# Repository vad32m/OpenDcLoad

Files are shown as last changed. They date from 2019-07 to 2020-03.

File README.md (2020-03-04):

#### Configurable parameters

| Configurable parameter | Range | Granularity | Number of Values |
| --- | --- | --- | --- |
| Current (CC mode) | 0 - 10 A | 10 mA | 1000 |
| Voltage (CV mode) | 1 - 10 V | 10 mV | 900 |
| | 10 - 100 V | 100 mV | 900 |
| | 100 - 360 V  | 1 V | 260 |
| Resistance (CR mode) | 0.5 - 10 Ohm | 50 mOhm | 190 |
| | 10 - 200 Ohm | 500 mOhm | 190 |
| Power (CP mode) | ???? | ???? | ???? |

#### Limits

| Limit type | Applicable mode | Limit value |
| --- | --- | --- |
| Power | All modes | 100 W max |
| Current | All modes | 10 A max |
| Voltage | All modes | 1 - 360 V |
| Resistance | All modes | 0.5 Ohm min |

#### Measured values

| Measured parameter | Range | Precision | Number of Values |
| --- | --- | --- | --- |
| Current | 0 - 1 A | 1 mA | 1000 |
| | 1 - 10 A | 10 mA | 900 |
| Voltage | 1 - 10 V | 10 mV | 900 |
| | 10 - 360 V | 100 mV | 3500 |

#### Parts

Power transistor - IRFP350

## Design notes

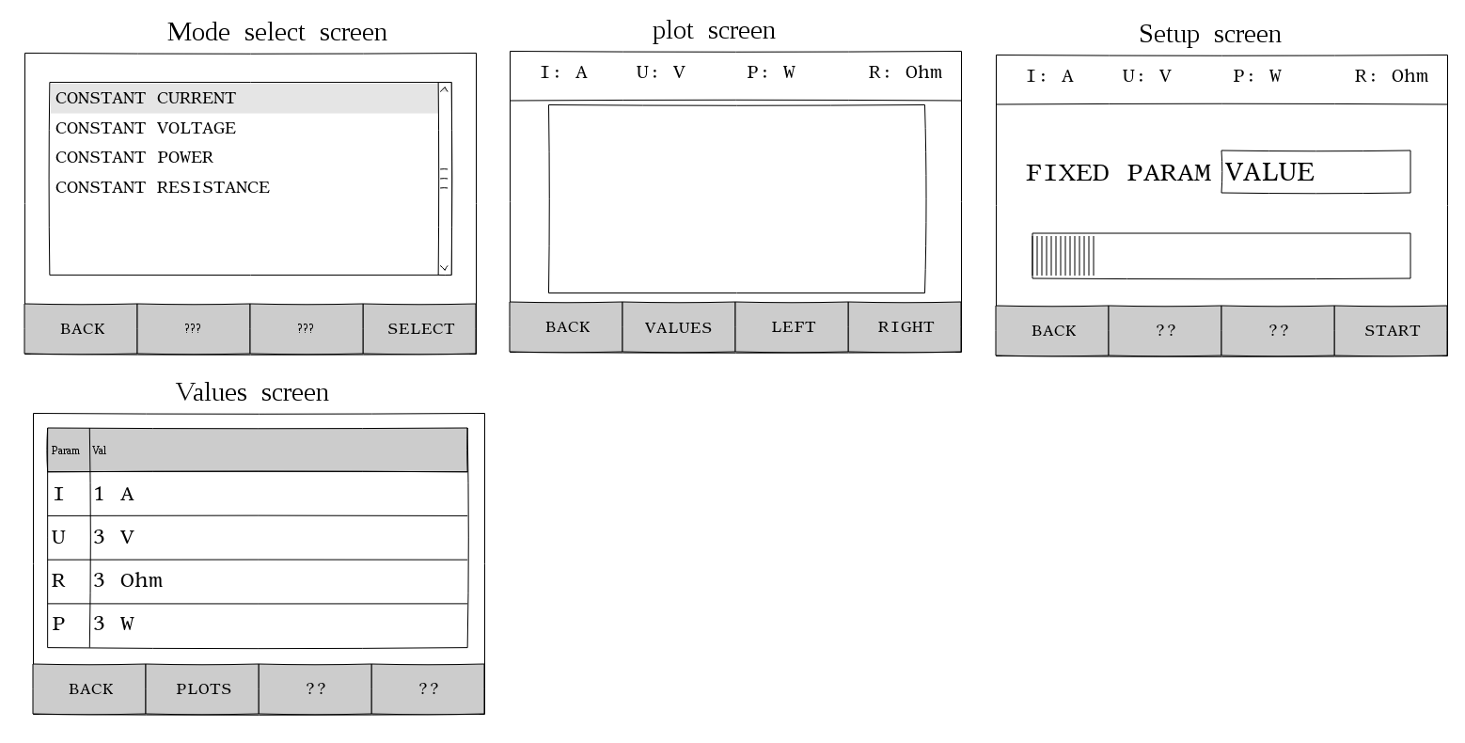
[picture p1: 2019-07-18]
doc/ui_wireframes.png

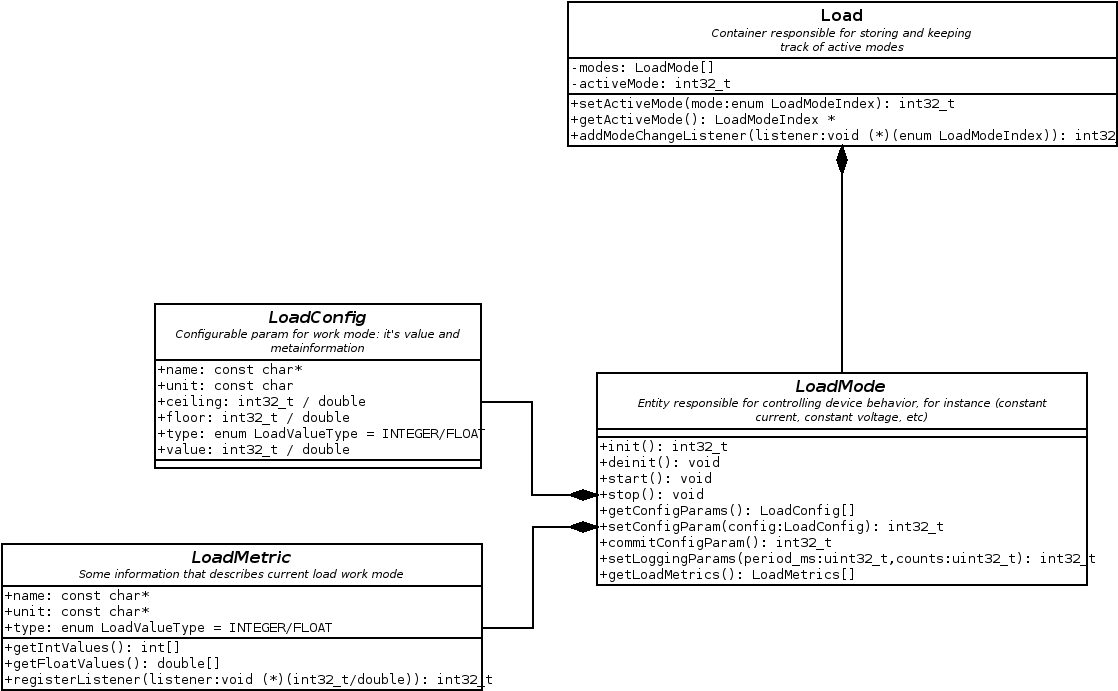
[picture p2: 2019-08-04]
doc/entities.png

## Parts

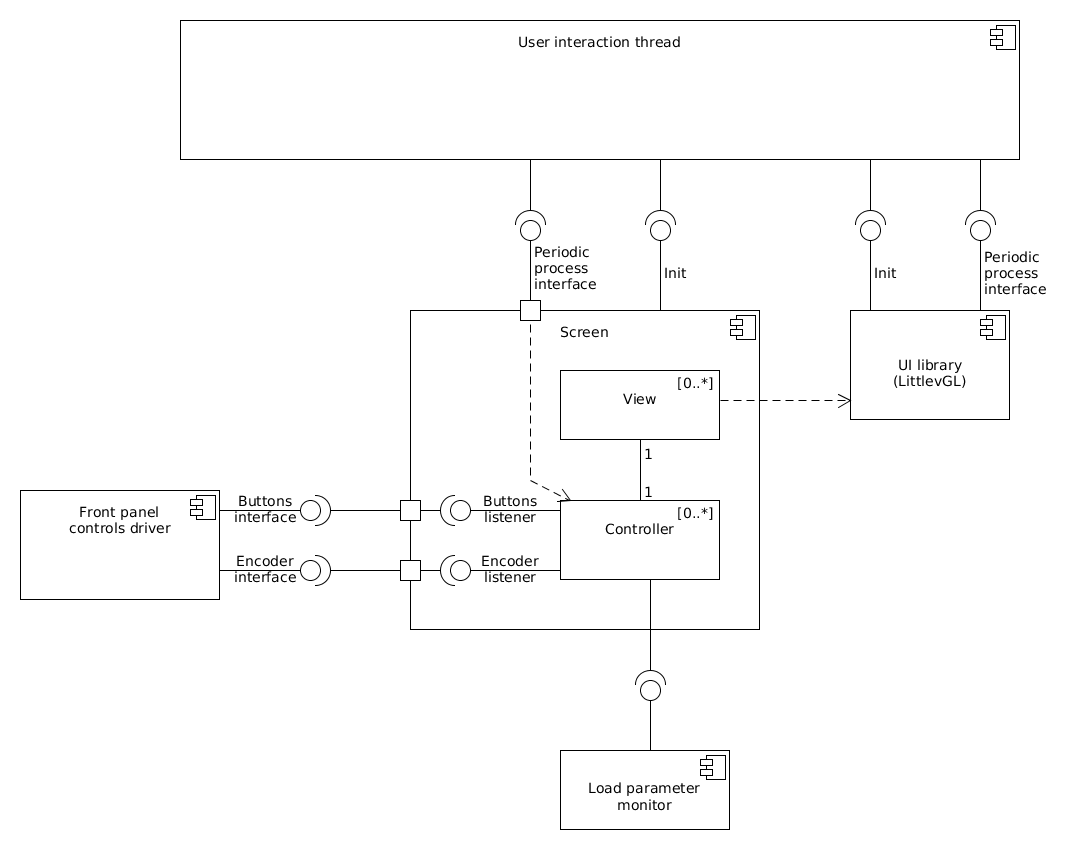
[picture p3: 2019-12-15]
doc/components.png

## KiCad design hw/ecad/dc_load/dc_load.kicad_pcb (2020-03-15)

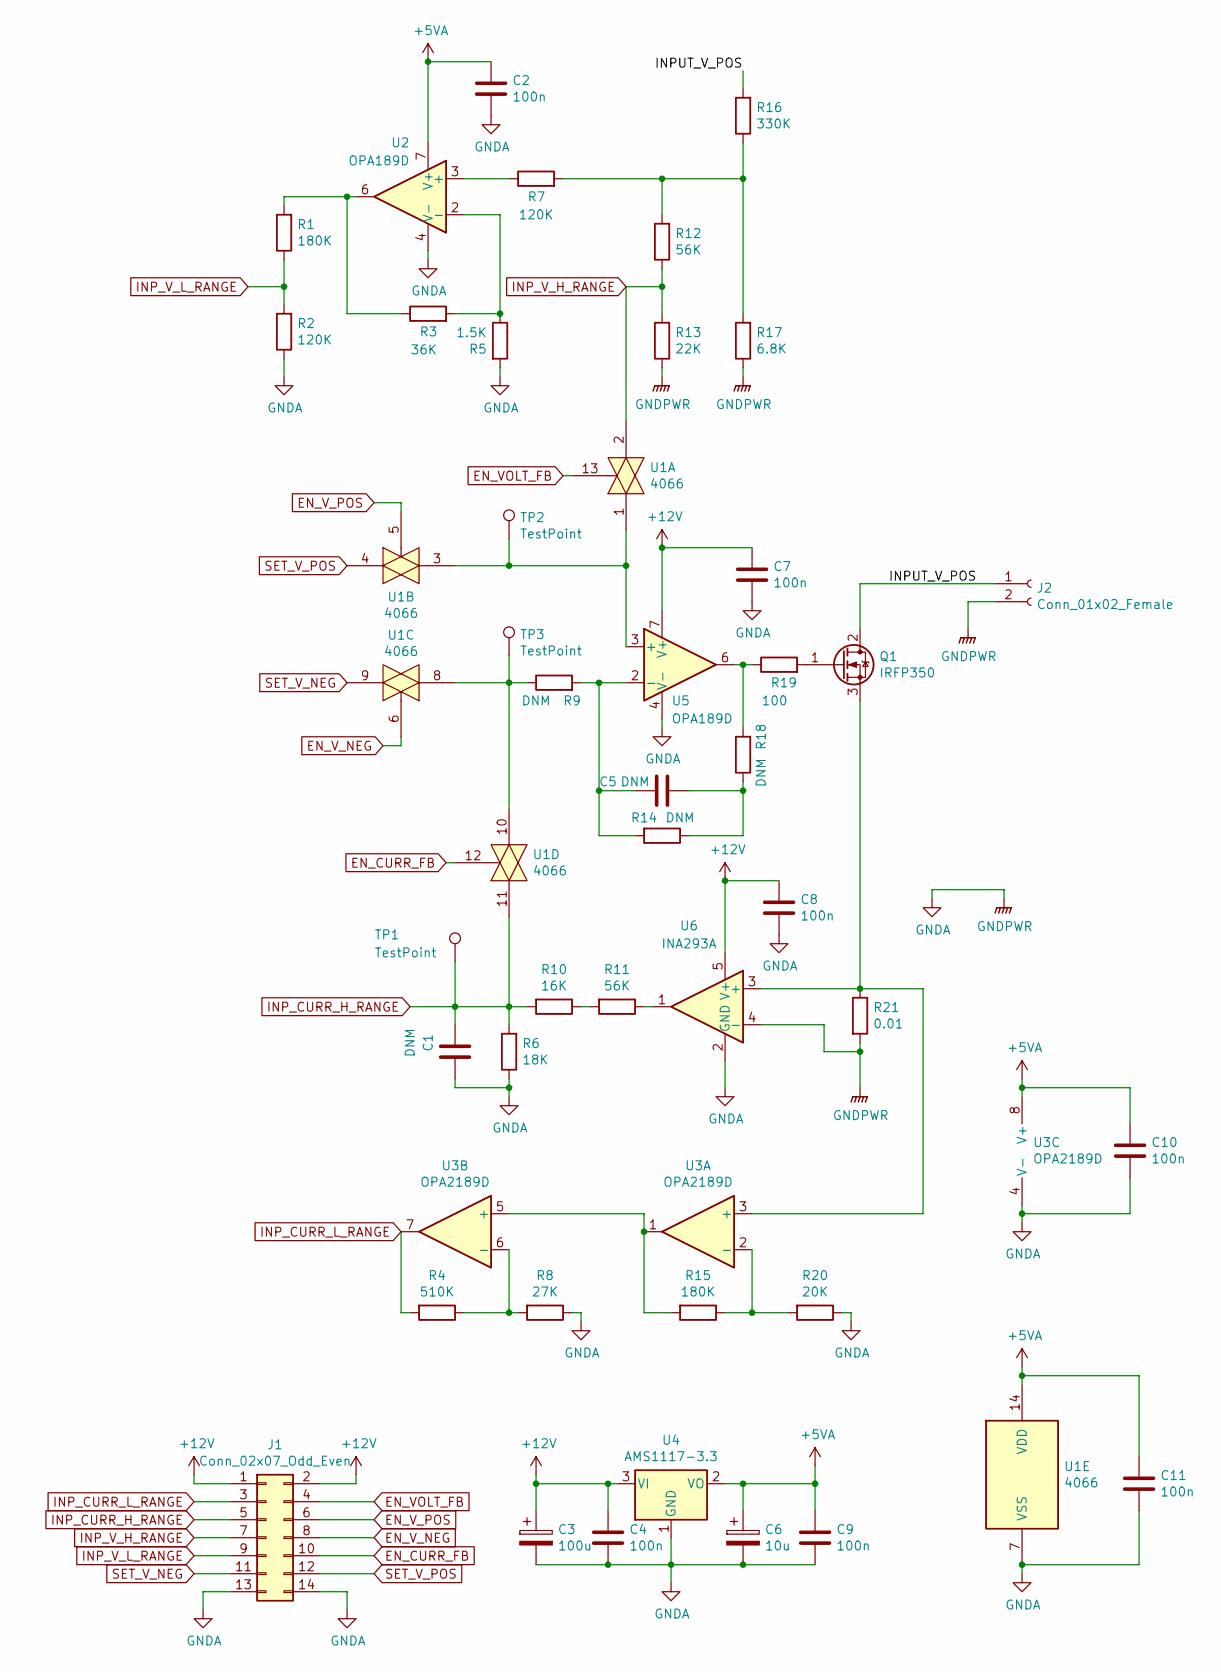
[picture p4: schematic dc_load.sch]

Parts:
C1, C5: DNM; C_0805_2012Metric_Pad1.15x1.40mm_HandSolder
C2, C4, C7, C8, C9, C10, C11: 100n; C_0805_2012Metric_Pad1.15x1.40mm_HandSolder
C3: 100u; CP_Radial_D7.5mm_P2.50mm
C6: 10u; CP_Radial_D5.0mm_P2.00mm
J1: Conn_02x07_Odd_Even; IDC-Header_2x07_P2.54mm_Vertical
J2: Conn_01x02_Female; SolderWirePad_1x02_P5.08mm_Drill1.5mm
Q1: IRFP350; TO-247-3_Horizontal_TabDown
R1, R15: 180K; R_0805_2012Metric_Pad1.15x1.40mm_HandSolder
R2, R7: 120K; R_0805_2012Metric_Pad1.15x1.40mm_HandSolder
R3: 36K; R_0805_2012Metric_Pad1.15x1.40mm_HandSolder
R4: 510K; R_0805_2012Metric_Pad1.15x1.40mm_HandSolder
R5: 1.5K; R_0805_2012Metric_Pad1.15x1.40mm_HandSolder
R6: 18K; R_0805_2012Metric_Pad1.15x1.40mm_HandSolder
R8: 27K; R_0805_2012Metric_Pad1.15x1.40mm_HandSolder
R9, R14, R18: DNM; R_0805_2012Metric_Pad1.15x1.40mm_HandSolder
R10: 16K; R_0805_2012Metric_Pad1.15x1.40mm_HandSolder
R11, R12: 56K; R_0805_2012Metric_Pad1.15x1.40mm_HandSolder
R13: 22K; R_0805_2012Metric_Pad1.15x1.40mm_HandSolder
R16: 330K; R_0805_2012Metric_Pad1.15x1.40mm_HandSolder
R17: 6.8K; R_0805_2012Metric_Pad1.15x1.40mm_HandSolder
R19: 100; R_0805_2012Metric_Pad1.15x1.40mm_HandSolder
R20: 20K; R_0805_2012Metric_Pad1.15x1.40mm_HandSolder
R21: 0.01; R_4020_10251Metric_Pad1.65x5.30mm_HandSolder
TP1, TP2, TP3: TestPoint; TestPoint_Pad_D1.5mm
U1: 4066; SOIC-14_3.9x8.7mm_P1.27mm
U2, U5: OPA189D; SOIC-8_3.9x4.9mm_P1.27mm
U3: OPA2189D; SOIC-8_3.9x4.9mm_P1.27mm
U4: AMS1117-3.3; SOT-223-3_TabPin2
U6: INA293A; SOT-23-5

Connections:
+5VA: C2.1, C6.1, C9.1, C10.1, C11.1, U1.14 (VDD), U2.7 (V+), U3.8 (V+), U4.2 (VO)
+12V: C3.1, C4.1, C7.1, C8.1, J1.1, J1.2, U4.3 (VI), U5.7 (V+), U6.5 (V+)
/INPUT_V_POS: J2.1, Q1.2 (D), R16.2
EN_CURR_FB: J1.10, U1.12
EN_VOLT_FB: J1.4, U1.13
EN_V_NEG: J1.8, U1.6
EN_V_POS: J1.6, U1.5
GNDA: C1.2, C2.2, C3.2, C4.2, C6.2, C7.2, C8.2, C9.2, C10.2, C11.2, J1.13, J1.14, J2.2, R2.1, R5.2, R6.1, R8.1, R13.1, R17.1, R20.1, R21.2, U1.7 (VSS), U2.4 (V-), U3.4 (V-), U4.1 (GND), U5.4 (V-), U6.2 (GND), U6.4 (-)
INP_CURR_H_RANGE: C1.1, J1.5, R6.2, R10.2, TP1.1, U1.11
INP_CURR_L_RANGE: J1.3, R4.2, U3.7
INP_V_H_RANGE: J1.7, R12.1, R13.2, U1.2
INP_V_L_RANGE: J1.9, R1.1, R2.2
unnamed: C5.1, R9.2, R14.2, U5.2 (-)
unnamed: C5.2, R14.1, R18.1
unnamed: Q1.1 (G), R19.2
unnamed: Q1.3 (S), R21.1, U3.3 (+), U6.3 (+)
unnamed: R1.2, R3.1, U2.6
unnamed: R3.2, R5.1, U2.2 (-)
unnamed: R4.1, R8.2, U3.6 (-)
unnamed: R7.1, U2.3 (+)
unnamed: R9.1, TP3.1, U1.8, U1.10
unnamed: R10.1, R11.2
unnamed: R11.1, U6.1
unnamed: R7.2, R12.2, R16.1, R17.2
unnamed: R15.1, R20.2, U3.2 (-)
unnamed: R15.2, U3.1, U3.5 (+)
unnamed: R18.2, R19.1, U5.6
unnamed: TP2.1, U1.1, U1.3, U5.3 (+)
SET_V_NEG: J1.11, U1.9
SET_V_POS: J1.12, U1.4

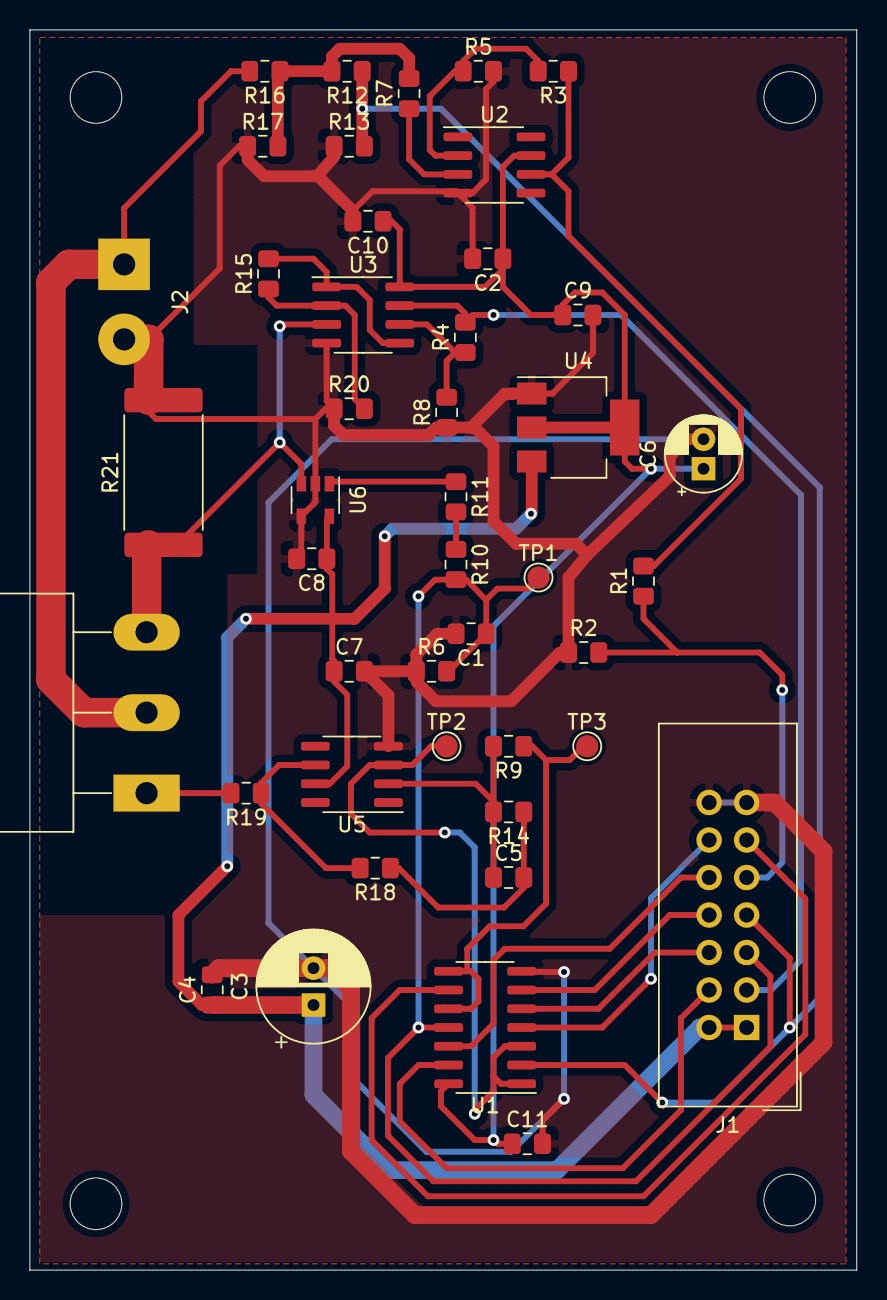
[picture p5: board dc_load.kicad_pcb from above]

Board: 2 copper layers, 56.0 x 84.0 mm, 44 parts (0 on the bottom side), 30 nets.

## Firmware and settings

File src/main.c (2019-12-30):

#include <libopencm3/stm32/gpio.h>
#include <libopencm3/stm32/rcc.h>

#include <stdlib.h>
#include <string.h>
#include <stdio.h>

#include "FreeRTOS.h"
#include "task.h"
#include "debug/logging.h"
#include "debug/assertions.h"
#include "platform/core_setup.h"
#include "platform/display_connection.h"

#include "ui/user_interaction_process.h"
#include "ui/screen.h"

#include "app/work_mode_facade.h"


static void
gpio_setup(void)
{
   /* Enable GPIOC clock. */
   rcc_periph_clock_enable(RCC_GPIOA);
   rcc_periph_clock_enable(RCC_GPIOB);

   /* Set GPIO8 (in GPIO port C) to 'output push-pull'. */
   gpio_mode_setup(GPIOA, GPIO_MODE_OUTPUT, GPIO_PUPD_NONE, GPIO7);
   gpio_mode_setup(GPIOB, GPIO_MODE_AF, GPIO_PUPD_NONE, GPIO3);
   gpio_set_af(GPIOB, GPIO_AF0, GPIO3);
}

struct display_driver display;

#define TEST_NULL_DEREF 0
#define TEST_BUS_FAULT 0
#define TEST_USAGE_FAULT 0
#define TEST_MEMMANAG_FAULT 0
#define TEST_DIV0_FAULT 0
#define TEST_OUT_OF_MEMORY 0

int
main(void)
{
    clock_setup();
    systick_setup();
    gpio_setup();
    irq_setup();
    logger_init();
    display_connection_init();
    display_init(&display, displayOrientationHorizontalFlipped);


#if !TEST_BUS_FAULT
    mpu_setup();
#endif

#if TEST_OUT_OF_MEMORY
    for (int i = 0; true; i++)
    {
        volatile char *example = malloc(2048);

        if (example)
        {
            *example = 10;
        }
        else
        {
            puts(strerror(errno));
        }
    }
#endif


#if TEST_NULL_DEREF
    volatile int* null_ptr = 0;
    volatile int a = *null_ptr;
#endif

#if TEST_BUS_FAULT
    //trigger precise bus fault by accessing memory behind the end of the RAM
    extern int _stack;
    int* behind_the_end = &_stack + 4;
    volatile int a = *behind_the_end;
#endif

#if TEST_USAGE_FAULT
    __asm volatile("udf.w");
#endif

#if TEST_MEMMANAG_FAULT
    void (*exec_never_region)(void) = 0x40000000;
    exec_never_region();
#endif

#if TEST_DIV0_FAULT
    int a = 0;
    volatile int b = 10/a;
#endif

    wm_facade_init(3);
    user_interaction_init(&display);
    user_interaction_start_process(4);
    ui_screen_t* scr = screen_get_instance();
    screen_set_active(scr, UI_SCREEN_MODE_SELECT);

    vTaskStartScheduler();

    for (;;);
    return 0;
}

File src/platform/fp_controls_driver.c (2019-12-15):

#include "platform/fp_controls_driver.h"
#include <libopencm3/stm32/gpio.h>
#include <libopencm3/stm32/rcc.h>
#include <libopencm3/stm32/timer.h>

typedef struct {;
    uint32_t port;
    uint32_t pin;
} button_pin_t;

button_pin_t buttons[BTN_MAX_INDEX];

void buttons_init()
{
    buttons[BTN_LEFT].port = GPIOE; buttons[BTN_LEFT].pin = GPIO3;
    buttons[BTN_MID_LEFT].port = GPIOE; buttons[BTN_MID_LEFT].pin = GPIO4;
    buttons[BTN_MID_RIGHT].port = GPIOE; buttons[BTN_MID_RIGHT].pin = GPIO5;
    buttons[BTN_RIGHT].port = GPIOE; buttons[BTN_RIGHT].pin = GPIO6;
    buttons[BTN_ENCODER].port = GPIOC; buttons[BTN_ENCODER].pin = GPIO13;

    rcc_periph_clock_enable(RCC_GPIOE);
    rcc_periph_clock_enable(RCC_GPIOC);

    for (uint8_t i = 0; i < BTN_MAX_INDEX; i++)
    {
        gpio_mode_setup(buttons[i].port, GPIO_MODE_INPUT, GPIO_PUPD_PULLUP, buttons[i].pin);
    }

}

bool button_is_pressed(button btn)
{
    return !gpio_get(buttons[btn].port, buttons[btn].pin);
}

int32_t encoder_init(void)
{
    rcc_periph_clock_enable(RCC_GPIOB);
    gpio_mode_setup(GPIOB, GPIO_MODE_AF, GPIO_PUPD_PULLUP, GPIO7 | GPIO6);
    gpio_set_af(GPIOB, GPIO_AF2, GPIO7 | GPIO6);

    rcc_periph_clock_enable(RCC_TIM3);
    timer_set_period(TIM4, 1024);
    timer_slave_set_mode(TIM4, 0x3); // encoder
    timer_ic_set_input(TIM4, TIM_IC1, TIM_IC_IN_TI1);
    timer_ic_set_input(TIM4, TIM_IC2, TIM_IC_IN_TI2);
    timer_enable_counter(TIM4);
}

int32_t encoder_get_count_and_dir(uint32_t* count, encoder_dir* dir)
{
    *count = timer_get_counter(TIM4);
    *dir = (TIM14_CCR1 | TIM_CR1_DIR_DOWN) ? ENCODER_DIR_BACKWARD : ENCODER_DIR_FORWARD;
}

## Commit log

2019-03-09 Project setup: configure SWV pin and add SWO printf
2019-04-23 project setup: move fault interrupts to separate file
2019-05-05 project setup: configure interrupts priority
2019-05-15 debug subsystem: add interrupt configuration for logger
2019-07-04 lcd driver: add initial version of the display driver
2019-07-08 periph config: utilize DMA for bulk data transfer on display connection
2019-07-08 lcd driver: use optimized function for display fill
2019-07-14 lcd driver: fix magic numbers and orientation flags
    [display_connection.c, main.c]
2019-07-14 display connection: add check to preserve DMA transactions overlap
2019-07-14 ldc driver: forward callbacks on bulk data transfers completed
2019-07-18 ui: add wireframes for basic work modes
2019-08-04 display to lvgl glue: move to separate file
2019-09-22 ui: update lvgl submodule and add example with secondary Y-axis
2019-12-08 ui: add files with layout and replace magic numbers with constants
    [basic_view_layout.h, param_setup_view_layout.h]
2019-12-10 debug subsystem: add assertion for checking whether current expression is NULL
2019-12-10 ui: add assertions and error codes to views
    [basic_view_layout.h, param_setup_view_layout.h]
2019-12-10 ui: rework mechanism of view activation, improve buttons control
    [basic_view_layout.h]
2019-12-15 ftont_panel_controls: initial implemetation of the buttons and encoder driver
2020-03-04 hardware: add circuit that combines CV, CC and CR mode frontend
2020-03-15 hardware: add more precise voltage divider for sensing input voltage
2020-03-15 hardware: add ecad project: schematic and PCB
    [dc_load.kicad_pcb, dc_load.sch]
